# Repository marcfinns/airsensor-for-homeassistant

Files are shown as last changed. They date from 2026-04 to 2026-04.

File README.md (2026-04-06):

# AirSensor

A multi-room air quality monitor built around ESPHome and Home Assistant. Each unit sits flush on the wall like a light switch — mains powered, fully self-contained, nothing to charge or manage. Built on the ESP32-C6, it is hardware-ready for Matter, making it future-proof as smart home standards evolve.

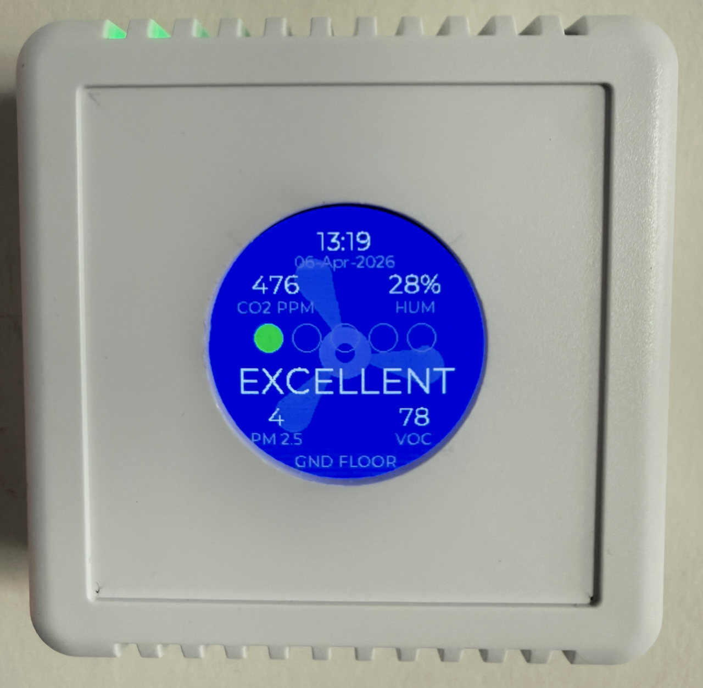
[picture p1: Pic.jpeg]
AirSensor unit installed on the wall


---

## What it measures

Each unit reports the following to Home Assistant in real time:

| Sensor | Measurements |
|---|---|
| **Sensirion SEN55** | PM1.0, PM2.5, PM4.0, PM10 · VOC Index · NOx Index · Temperature · Humidity |
| **Sensirion SCD4x** | CO2 (ppm) · Temperature · Humidity |
| **Infineon DPS310** *(optional)* | Barometric pressure · Temperature |

The DPS310 pressure sensor is fitted on one unit only and is entirely optional — the PCB and firmware support it but work fine without it.

---

## Display

Each unit has a **GC9A01A 240×240 round TFT** (SPI), sourced from AliExpress:

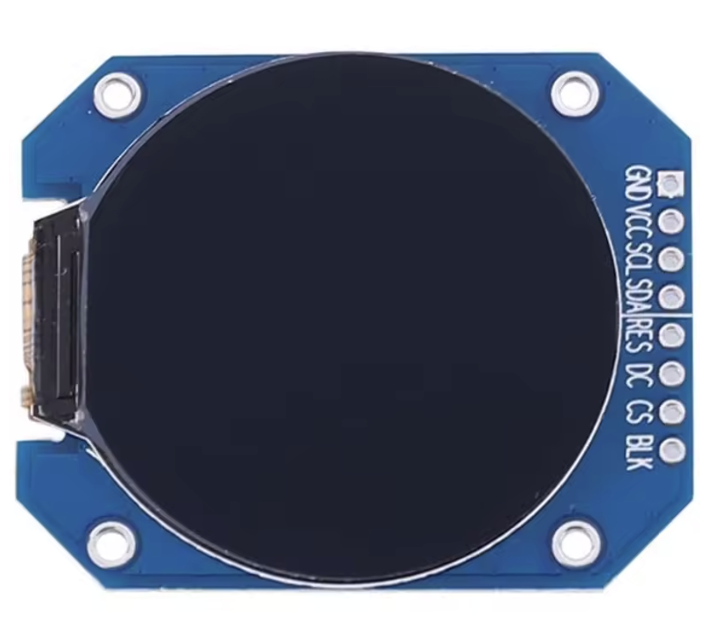
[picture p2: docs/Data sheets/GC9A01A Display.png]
GC9A01A round display module


The display shows:
- **Time and date** (synced from Home Assistant)
- **CO2, humidity, PM2.5, VOC** values in the four quadrants
- A **5-segment AQI bar** reflecting the worst pollutant level across all sensors, colour-coded from green (Excellent) to red (Very Poor)
- A large **status word** (EXCELLENT / GOOD / FAIR / POOR / VERY POOR) at the centre
- An **animated fan graphic** as the background (see below)

The XIAO's built-in RGB LED *(optional)* breathes in the AQI colour — green through red depending on air quality — visible from across the room without looking at the display. It can be enabled or disabled from Home Assistant and the state persists across reboots.

---

## Animated fan

A **Fan Speed** entity (Off / Low / High) is exposed in Home Assistant. Selecting Low or High drives an animated three-blade fan spinning in the background of the display — slow and blue-purple at Low, faster and brighter purple at High. It is purely decorative and does not control any physical hardware. The selected speed persists across reboots.

---

## Hardware

| Component | Role |
|---|---|
| Seeed XIAO ESP32-C3 | MCU — different GPIO layout, otherwise identical firmware |
| Seeed XIAO ESP32-C6 | MCU — preferred variant; Wi-Fi 6, Matter-capable radio |
| Sensirion SEN55 | Particulate matter + VOC + NOx + T/RH |
| Sensirion SCD4x | CO2 + T/RH |
| Infineon DPS310 breakout | Barometric pressure *(optional)* |
| GC9A01A 240×240 round TFT | Round display (AliExpress) |
| Kradex Z123_W | Enclosure — standard wall-mount junction box |

The ESP32-C6 is the preferred variant. Its Wi-Fi 6 and IEEE 802.15.4 radio make it hardware-ready for Matter once ESPHome's Matter support matures. The C3 lacks the necessary radio and cannot support Matter.

---

## PCB

A single custom PCB designed in KiCad houses the MCU, sensors, and display connector inside the Kradex enclosure.

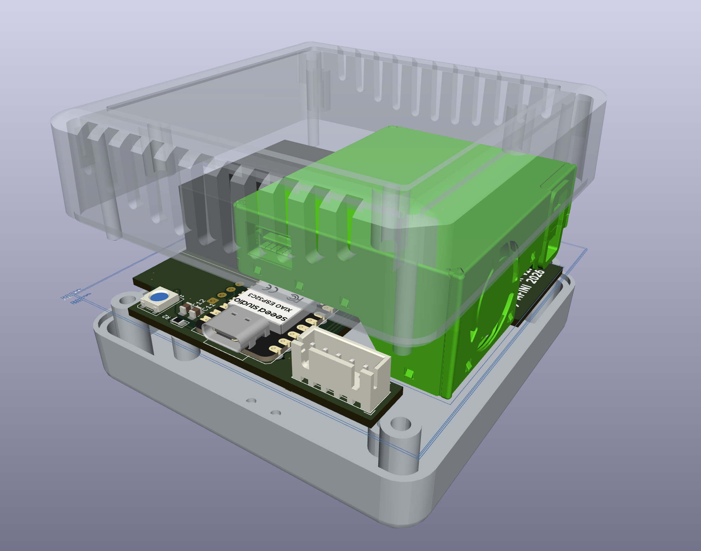
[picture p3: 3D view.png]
KiCad 3D render


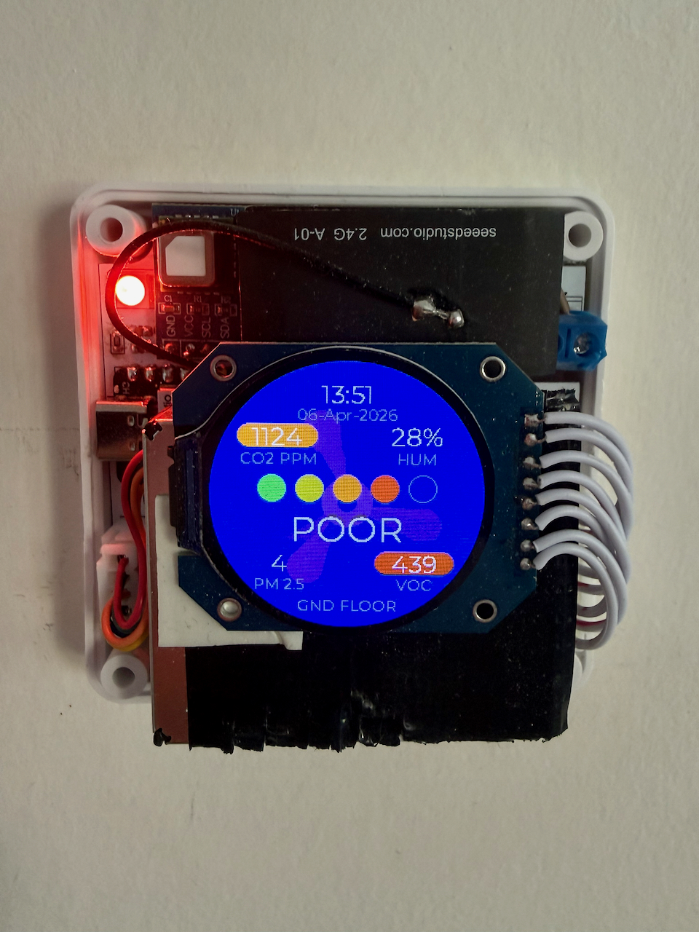
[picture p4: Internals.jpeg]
Internals — PCB, display and wiring mounted in the enclosure


Custom KiCad libraries (symbols, footprints, and 3D models) are kept under `lib/` and referenced with portable `${KIPRJMOD}`-relative paths so the project opens correctly on any machine.

---

## Home Assistant integration

Each unit exposes the following entities:

- **Sensors** — all measured values listed above
- **Fan Speed** — select (Off / Low / High) to control the display animation
- **Status LED** — switch to enable or disable the breathing LED
- **Display Backlight** — light entity with brightness control
- **Restart** — button to reboot the device OTA

---

## MCU variants

| | ESP32-C3 | ESP32-C6 |
|-|---|---|
| Wi-Fi | 802.11 b/g/n | 802.11 b/g/n/ax (Wi-Fi 6) |
| BLE | 5.0 | 5.3 |
| Matter (future) | No — hardware limitation | Yes — IEEE 802.15.4 radio |
| GPIO | Different pinout | Reference pinout |

Two reference templates are provided — `ESPHome_config/AirSensor-C3.yaml` and `AirSensor-C6.yaml` — covering both variants.

---

## Repository structure

```
AirSensor/
├── ESPHome_config/
│   ├── AirSensor-C3.yaml          # Reference template (ESP32-C3)
│   ├── AirSensor-C6.yaml          # Reference template (ESP32-C6)
│   ├── airsensor_aqi_helpers.h    # Shared AQI logic (C++)
│   ├── secrets.yaml               # Empty secrets template
│   └── private/                   # Real deployment configs (gitignored)
├── kicad/
│   └── AirSensor_display/         # KiCad project (schematic + PCB)
├── lib/
│   ├── symbols/                   # Custom KiCad symbols
│   ├── footprints/                # Custom KiCad footprints
│   └── 3d/                        # 3D models for KiCad
├── mech/                          # Enclosure and module STEP files
└── docs/
    └── Data sheets/               # Component datasheets
```

---

## Getting started

1. Copy `ESPHome_config/AirSensor-C3.yaml` or `AirSensor-C6.yaml` to `ESPHome_config/private/<unit-name>.yaml`
2. Fill in `ESPHome_config/private/secrets.yaml` (Wi-Fi credentials, API key, OTA password)
3. Search for `← CONFIGURE` markers in the YAML and update each one (device name, floor label, etc.)
4. Remove the DPS310 sensor block if the pressure sensor is not fitted
5. Flash via ESPHome: `esphome run private/<unit-name>.yaml`

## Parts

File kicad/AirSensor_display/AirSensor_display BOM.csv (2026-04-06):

Reference | Qty | Value | DNP | Exclude from BOM | Exclude from Board | Footprint | Datasheet
C1,C2,C5,C9,C11,C13 | 6 | 100nF |  |  |  | Capacitor_SMD:C_0805_2012Metric_Pad1.18x1.45mm_HandSolder | ~
C3,C4 | 2 | 47uF |  |  |  | Capacitor_SMD:C_0805_2012Metric_Pad1.18x1.45mm_HandSolder | ~
C6,C10,C12,C14 | 4 | 22uF |  |  |  | Capacitor_SMD:C_0805_2012Metric_Pad1.18x1.45mm_HandSolder | ~
D1 | 1 | WS2812B |  |  |  | LED_SMD:LED_WS2812B_PLCC4_5.0x5.0mm_P3.2mm | https://cdn-shop.adafruit.com/datasheets/WS2812B.pdf
D2 | 1 | SS12 |  |  |  | Diode_SMD:D_SMA | https://www.vishay.com/docs/88746/ss12.pdf
FB1 | 1 | 600ohm@100mhz |  |  |  | Inductor_SMD:L_0805_2012Metric | ~
J1 | 1 | SEN55 |  |  |  | Connector_JST:JST_XH_B5B-XH-A_1x05_P2.50mm_Vertical | ~
J2 | 1 | Screw_Terminal_01x02 |  |  |  | TerminalBlock_Phoenix:TerminalBlock_Phoenix_MKDS-1,5-2-5.08_1x02_P5.08mm_Horizontal | ~
J4 | 1 | Display |  |  |  | Connector_JST:JST_XH_B8B-XH-AM_1x08_P2.50mm_Vertical | ~
PS2 | 1 | HLK-PM01 |  |  |  | Converter_ACDC:Converter_ACDC_Hi-Link_HLK-PMxx | https://h.hlktech.com/download/ACDC%E7%94%B5%E6%BA%90%E6%A8%A1%E5%9D%973W%E7%B3%BB%E5%88%97/1/%E6%B5%B7%E5%87%8C%E7%A7%913W%E7%B3%BB%E5%88%97%E7%94%B5%E6%BA%9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
R2 | 1 | 220R |  |  |  | LED_SMD:LED_0805_2012Metric_Pad1.15x1.40mm_HandSolder | ~
R4 | 1 | 100R |  |  |  | LED_SMD:LED_0805_2012Metric_Pad1.15x1.40mm_HandSolder | ~
U1 | 1 | DC-DC 3V3 |  |  |  | Converter_DCDC:Converter_DCDC_Murata_OKI-78SR_Horizontal | https://power.murata.com/data/power/oki-78sr.pdf
U2 | 1 | DPS310 |  |  |  | AirSensor_footprints:DPS310_BREAKOUT
U3 | 1 | SCD41 |  |  |  | AirSensor_footprints:SCD41_BREAKOUT_1x4_2.54
U6 | 1 | MOUDLE-SEEEDUINO-XIAO-ESP32C3 |  |  |  | xiao ESP32C3_PCB:MOUDLE14P-SMD-2.54-21X17.8MM_PINONLY

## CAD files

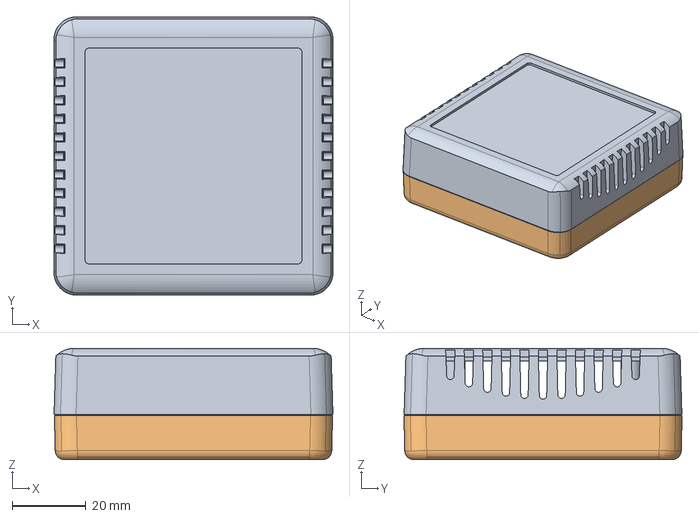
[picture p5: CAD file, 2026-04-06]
mech/Z123_W.stp
75.8 x 75.6 x 30.2 mm

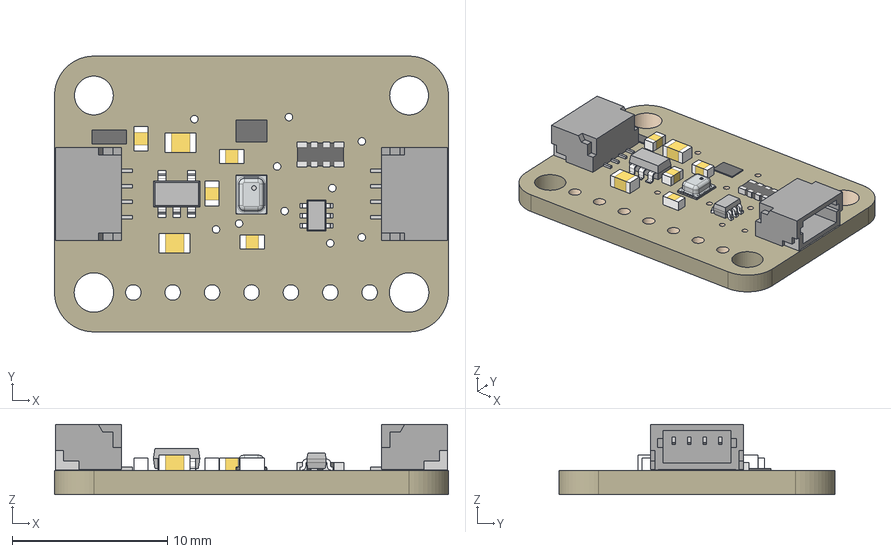
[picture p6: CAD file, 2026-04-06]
mech/4494-DPS310-Sensor.step
25.4 x 17.8 x 4.53 mm
Board
10uF x 2
AP2112K-3.3
10K x 4
10K_1
BSS138
STEMMA_I2C_QT x 2
GREEN
1N4148
BMX280_COMBO

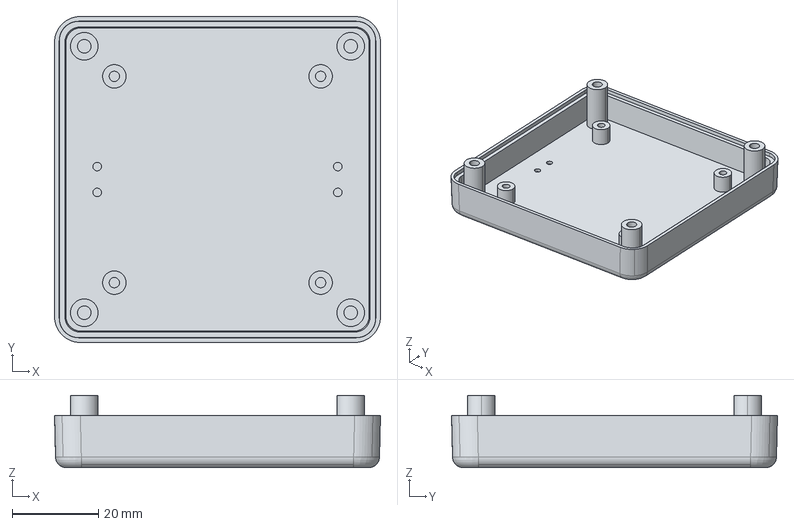
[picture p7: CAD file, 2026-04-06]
mech/Z123_W_BOTTOM.step
75.6 x 75.6 x 16.8 mm

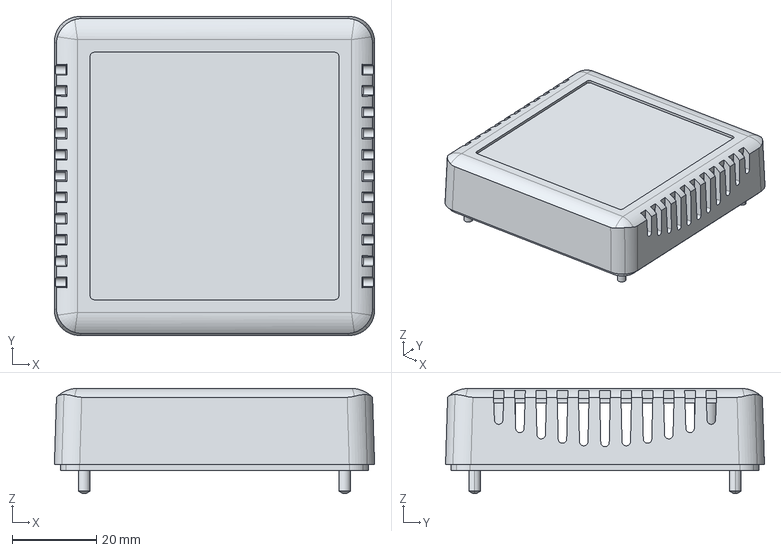
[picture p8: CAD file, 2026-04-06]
mech/Z123_W_TOP.step
75.8 x 75.5 x 24.9 mm

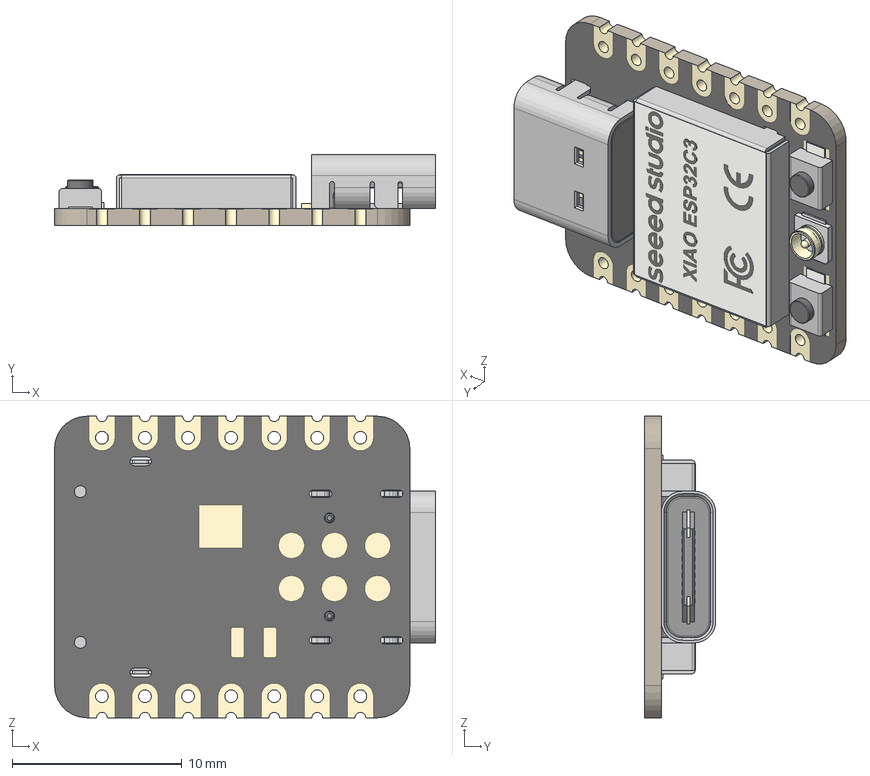
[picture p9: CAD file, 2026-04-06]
mech/seeed-studio-xiao-esp32-c3.step
22.5 x 4.21 x 17.8 mm
BOSS-EXTRUDE14_8_
BOSS-EXTRUDE7_4_
BOSS-EXTRUDE7_3_
BOSS-EXTRUDE14_4_
BOSS-EXTRUDE14_2_
BOSS-EXTRUDE14_11_
BOSS-EXTRUDE7_7_
BOSS-EXTRUDE14_9_
BOSS-EXTRUDE14_3_
BOSS-EXTRUDE14_7_
MIRROR2
BOSS-EXTRUDE14_5_
BOSS-EXTRUDE14_12_
BOSS-EXTRUDE7_8_
BOSS-EXTRUDE7_1_
BOSS-EXTRUDE14_10_
BOSS-EXTRUDE7_9_
BOSS-EXTRUDE14_6_
BOSS-EXTRUDE14_1_
BOSS-EXTRUDE7_6_
BOSS-EXTRUDE7_2_
CUT-EXTRUDE5
BOSS-EXTRUDE7_5_
U.FL Connector v1
Button (1) x 2
Shield

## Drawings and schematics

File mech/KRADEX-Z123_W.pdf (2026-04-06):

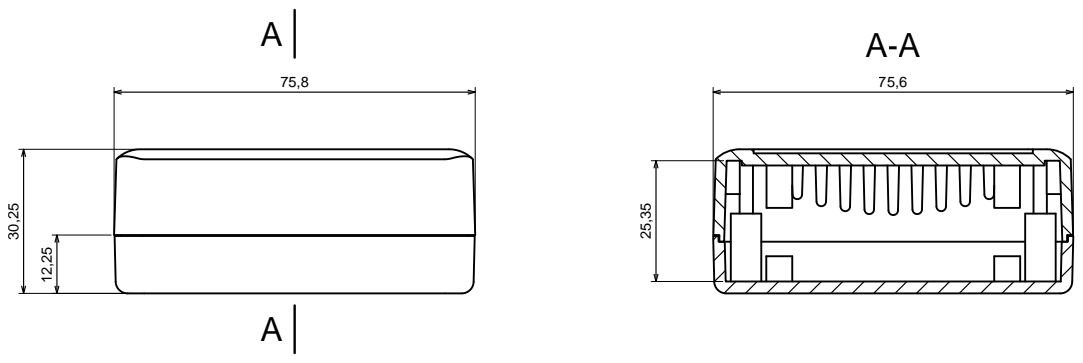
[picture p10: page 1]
Product model Format: A3 Scale 1:1; Tolerance: +/- 0.5 Material: PS, ABS Enclosure Z123 - assembly All rights reserved, Copyright Kradex 2016 AA

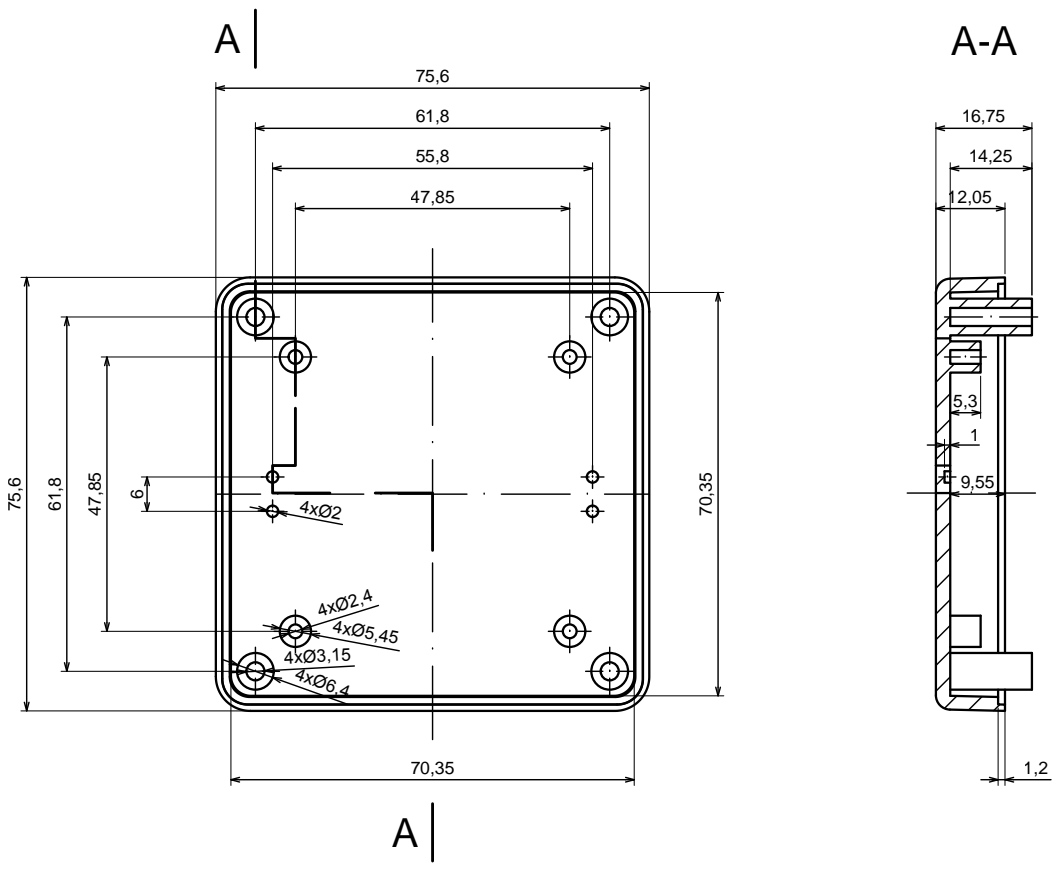
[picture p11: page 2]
Product model Format: A3 Scale 1:1; Tolerance: +/- 0.5 Material: PS, ABS Enclosure Z123 - base All rights reserved, Copyright Kradex 2016 A

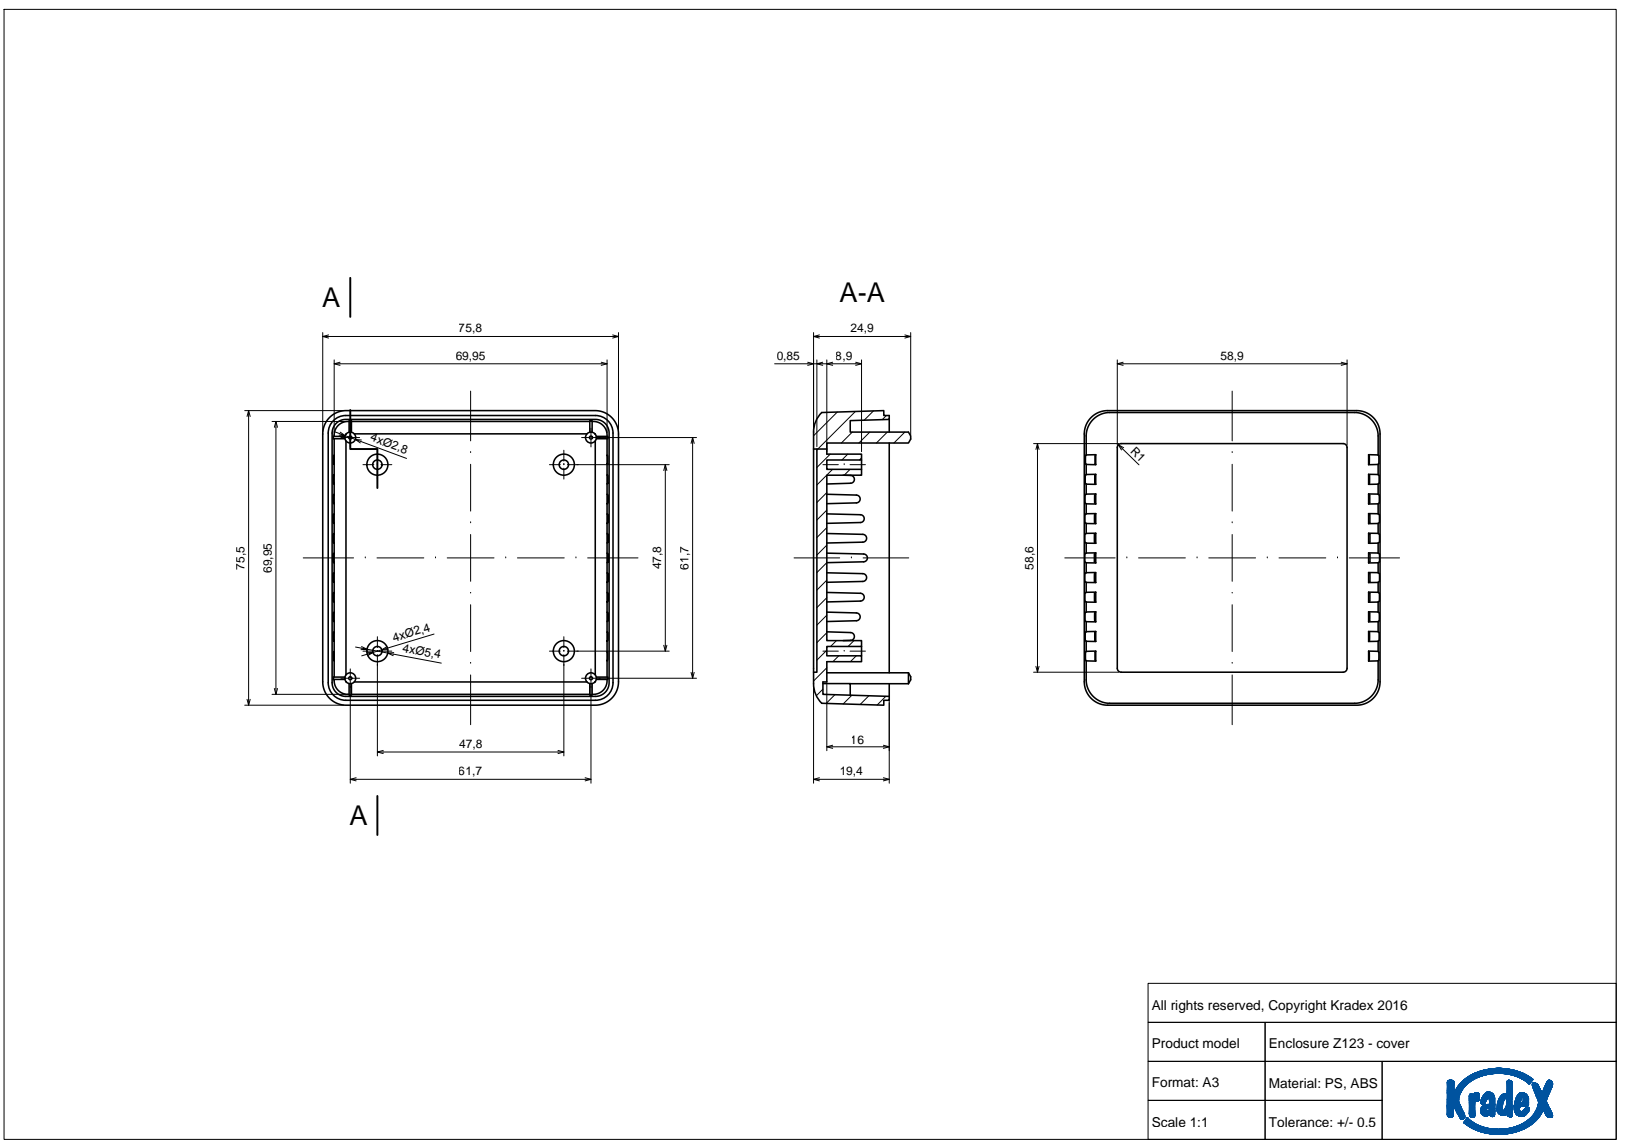
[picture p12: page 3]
Product model Format: A3 Scale 1:1; Tolerance: +/- 0.5 Material: PS, ABS Enclosure Z123 - cover All rights reserved, Copyright Kradex 2016 A A

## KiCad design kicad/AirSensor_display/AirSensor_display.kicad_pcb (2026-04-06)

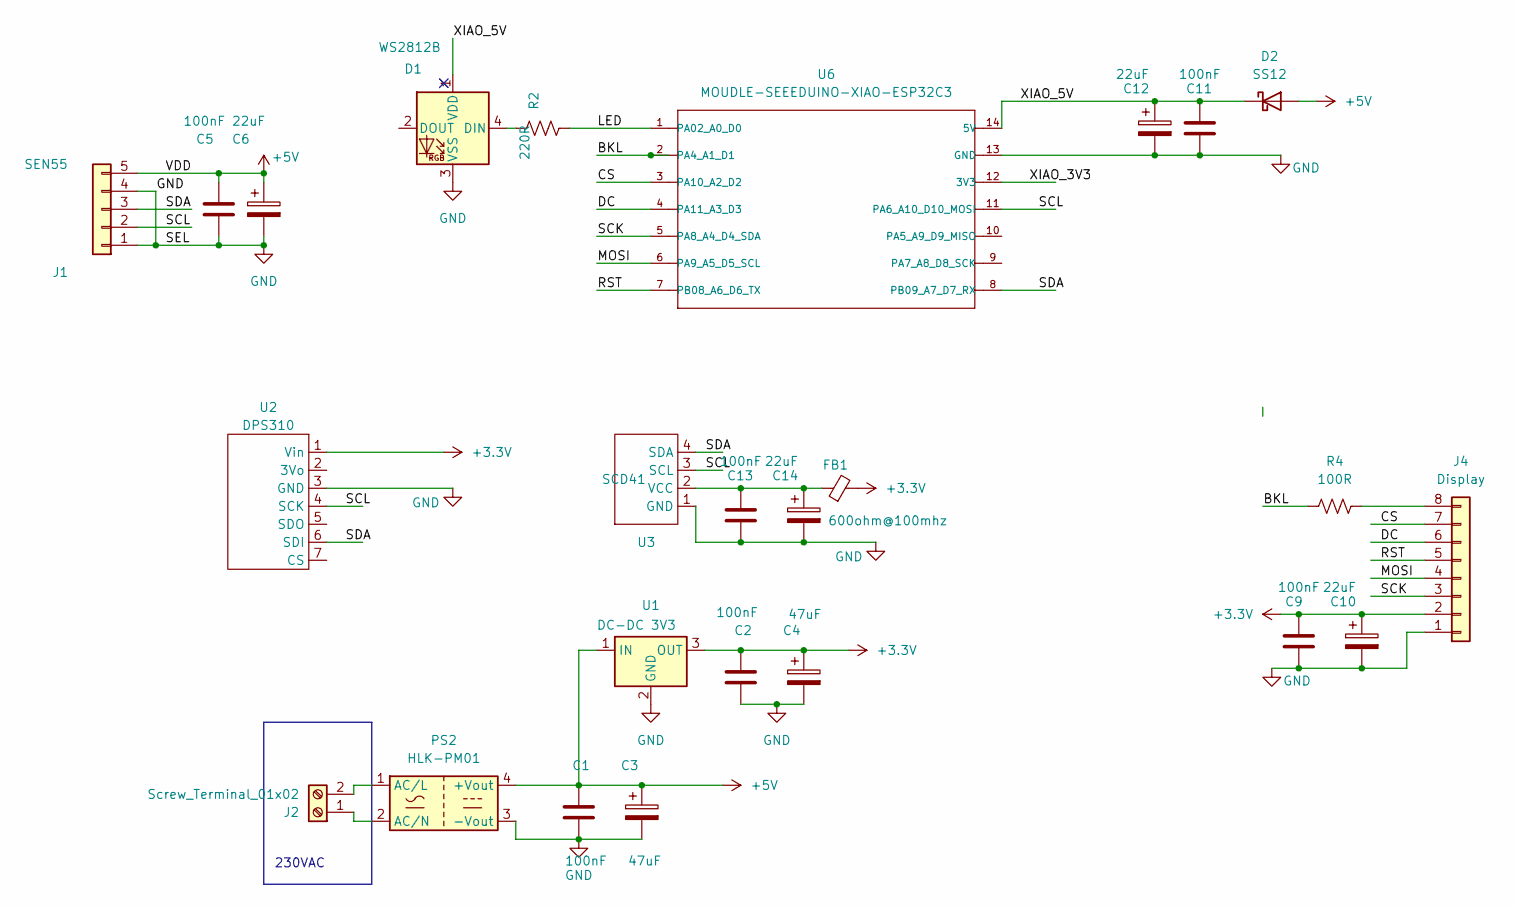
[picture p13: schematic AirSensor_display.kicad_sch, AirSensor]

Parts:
C1, C2, C5, C9, C11, C13: 100nF; C_0805_2012Metric_Pad1.18x1.45mm_HandSolder
C3, C4: 47uF; C_0805_2012Metric_Pad1.18x1.45mm_HandSolder
C6, C10, C12, C14: 22uF; C_0805_2012Metric_Pad1.18x1.45mm_HandSolder
D1: WS2812B; LED_WS2812B_PLCC4_5.0x5.0mm_P3.2mm
D2: SS12; D_SMA
FB1: 600ohm@100mhz; L_0805_2012Metric
J1: SEN55; JST_XH_B5B-XH-A_1x05_P2.50mm_Vertical
J2: Screw_Terminal_01x02; TerminalBlock_Phoenix_MKDS-1,5-2-5.08_1x02_P5.08mm_Horizont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
J4: Display; JST_XH_B8B-XH-AM_1x08_P2.50mm_Vertical
PS2: HLK-PM01; Converter_ACDC_Hi-Link_HLK-PMxx
R2: 220R; LED_0805_2012Metric_Pad1.15x1.40mm_HandSolder
R4: 100R; LED_0805_2012Metric_Pad1.15x1.40mm_HandSolder
U1: DC-DC 3V3; Converter_DCDC_Murata_OKI-78SR_Horizontal
U2: DPS310; DPS310_BREAKOUT
U3: SCD41; SCD41_BREAKOUT_1x4_2.54
U6: MOUDLE-SEEEDUINO-XIAO-ESP32C3; MOUDLE14P-SMD-2.54-21X17.8MM_PINONLY

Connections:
+3.3V: C2.1, C4.1, C9.1, C10.1, FB1.2, J4.2, U1.3 (OUT), U2.1 (Vin)
+5V: C1.1, C3.1, C5.1, C6.1, D2.2 (A), J1.5, PS2.4 (+Vout), U1.1 (IN)
/BKL: R4.2, U6.2 (PA4_A1_D1)
/CS: J4.7, U6.3 (PA10_A2_D2)
/DC: J4.6, U6.4 (PA11_A3_D3)
/LED: R2.1, U6.1 (PA02_A0_D0)
/MOSI: J4.4, U6.6 (PA9_A5_D5_SCL)
/RST: J4.5, U6.7 (PB08_A6_D6_TX)
/SCK: J4.3, U6.5 (PA8_A4_D4_SDA)
/SCL: J1.2, U2.4 (SCK), U3.3 (SCL), U6.11 (PA6_A10_D10_MOSI)
/SDA: J1.3, U2.6 (SDI), U3.4 (SDA), U6.8 (PB09_A7_D7_RX)
/XIAO_3V3: U6.12 (3V3)
/XIAO_5V: C11.1, C12.1, D1.1 (VDD), D2.1 (K), U6.14 (5V)
GND: C1.2, C2.2, C3.2, C4.2, C5.2, C6.2, C9.2, C10.2, C11.2, C12.2, C13.2, C14.2, D1.3 (VSS), J1.1, J1.4, J4.1, PS2.3 (-Vout), U1.2 (GND), U2.3 (GND), U3.1 (GND), U6.13 (GND)
unnamed: D1.4 (DIN), R2.2
unnamed: J2.1, PS2.2 (AC/N)
unnamed: J2.2, PS2.1 (AC/L)
unnamed: J4.8, R4.1
unnamed: C13.1, C14.1, FB1.1, U3.2 (VCC)

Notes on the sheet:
230VAC

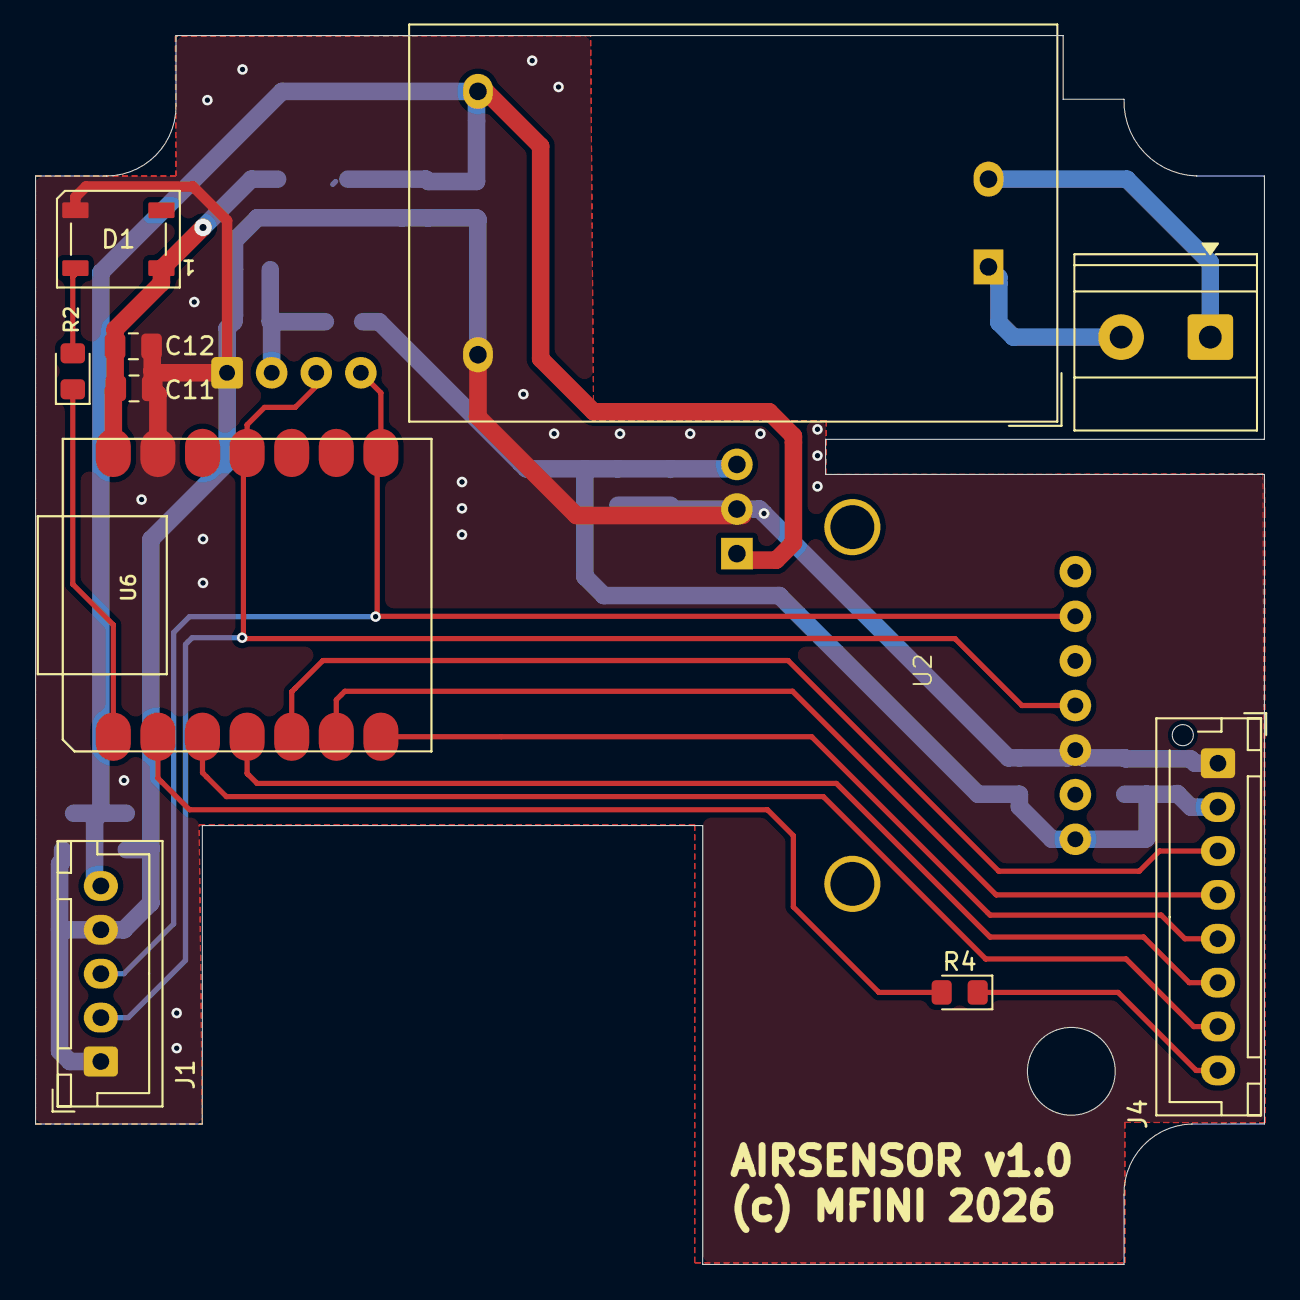
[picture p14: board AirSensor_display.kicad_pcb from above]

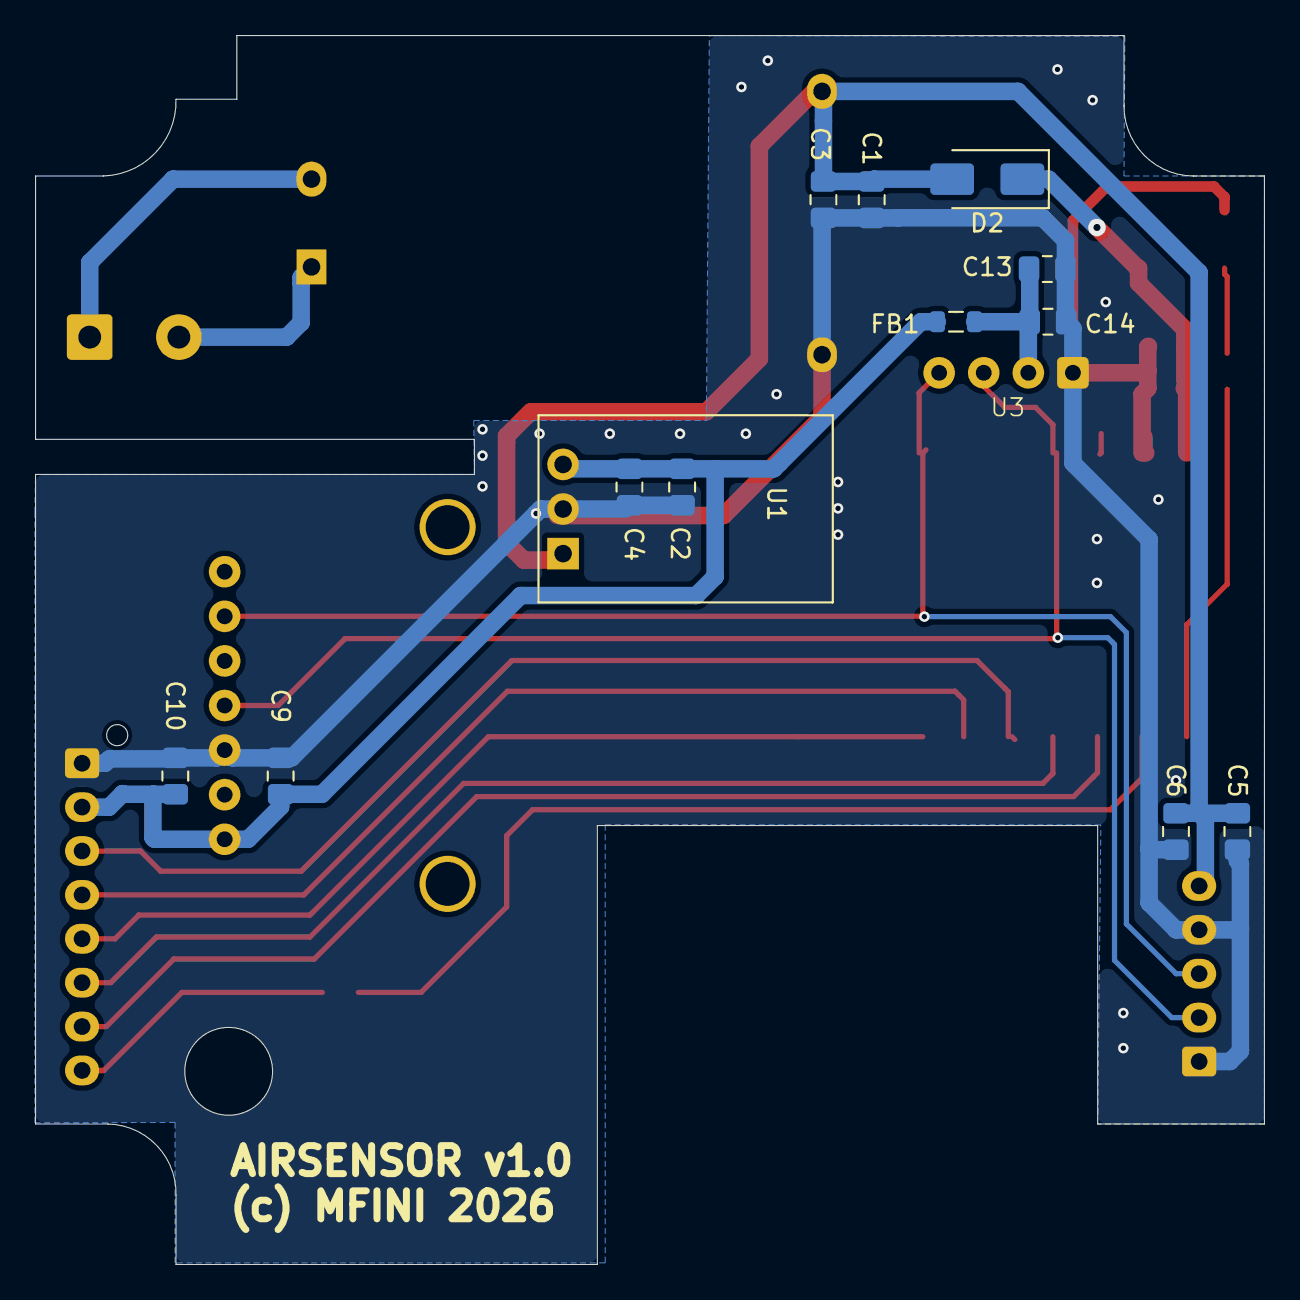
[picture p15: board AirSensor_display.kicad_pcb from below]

Board: 2 copper layers, 70.0 x 70.0 mm, 25 parts (14 on the bottom side), 18 nets.

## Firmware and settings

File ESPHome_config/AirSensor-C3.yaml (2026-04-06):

# =============================================================================
# AirSensor — Reference implementation for Seeed XIAO ESP32-C3
#
# MCU     : Seeed XIAO ESP32-C3
# Sensors : SEN55 (PM1/2.5/4/10, VOC, NOx, T, RH)
#           SCD4x (CO2, T, RH)
#           DPS310 (atmospheric pressure, optional — remove if not fitted)
# Display : GC9A01A 240×240 round TFT (SPI)
#
# To create a new unit from this template:
#   1. Copy to private/<unit-name>.yaml
#   2. Replace every value marked  ← CONFIGURE
#   3. Fill in private/secrets.yaml
# =============================================================================

esphome:
  name: airsensor-xxx            # ← CONFIGURE: unique lowercase device name
  friendly_name: Air Sensor XXX  # ← CONFIGURE: display name shown in HA
  includes:
    - ../airsensor_aqi_helpers.h   # AQI level/colour helpers shared by all units
  on_boot:
    # Priority -100 runs after all components are initialised.
    # Clears the boot-phase flag so the LED switch can start persisting state,
    # then publishes the restored LED enabled value to sync the HA entity.
    - priority: -100
      then:
        - lambda: |-
            id(g_boot_phase) = false;
            id(led_switch).publish_state(id(g_led_enabled));

# ---------------------------------------------------------------------------
# PREFERENCES
# ---------------------------------------------------------------------------
# Disable the automatic delayed-write to NVS flash.  Preference values
# (e.g. g_led_enabled) are written immediately when changed instead of
# being batched.  Keeps state reliable at the cost of slightly more flash
# wear on every toggle — acceptable given the low toggle frequency.
preferences:
  flash_write_interval: 0s

# ---------------------------------------------------------------------------
# MCU / FRAMEWORK
# ---------------------------------------------------------------------------
# ESP32-C3 — note different GPIO numbering compared to the C6 variant.
esp32:
  board: seeed_xiao_esp32c3
  variant: ESP32C3
  framework:
    type: esp-idf

# ---------------------------------------------------------------------------
# LOGGING
# ---------------------------------------------------------------------------
logger:
  level: INFO

# ---------------------------------------------------------------------------
# API / HOME ASSISTANT
# ---------------------------------------------------------------------------
api:
  encryption:
    key: !secret api_encryption_key

# Time source from Home Assistant (used for display)
time:
  - platform: homeassistant
    id: ha_time

# ---------------------------------------------------------------------------
# BLE / PROXY
# ---------------------------------------------------------------------------
# Kept for reference — disabled because enabling BLE on ESP32-C3 alongside
# Wi-Fi and a fast SPI display causes interference and CPU contention.
# bluetooth_proxy:
#   active: true
#
# esp32_ble_tracker:
#   scan_parameters:
#     interval: 1100ms
#     window: 1100ms
#     active: true

# ---------------------------------------------------------------------------
# OTA
# ---------------------------------------------------------------------------
ota:
  - platform: esphome
    password: !secret ota_password

# ---------------------------------------------------------------------------
# RESTART BUTTON (HOME ASSISTANT)
# ---------------------------------------------------------------------------
button:
  - platform: restart
    name: "AirSensor XXX Restart"  # ← CONFIGURE: match friendly_name

# ---------------------------------------------------------------------------
# WIFI
# ---------------------------------------------------------------------------
wifi:
  ssid: !secret wifi_ssid
  password: !secret wifi_password
  fast_connect: false
  power_save_mode: none
  ap:
    ssid: "AirSensor-XXX-Fallback"      # ← CONFIGURE: unique fallback SSID
    password: !secret fallback_hotspot_password

# ---------------------------------------------------------------------------
# HTTP UI (BASIC STATUS)
# ---------------------------------------------------------------------------
web_server:
  port: 80

# ---------------------------------------------------------------------------
# I2C BUS (SENSORS)
# ---------------------------------------------------------------------------
# C3 pinout: SDA=GPIO20, SCL=GPIO10.  SEN55, SCD4x and DPS310 share this bus.
i2c:
  sda: GPIO20
  scl: GPIO10
  scan: true
  id: bus_a
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

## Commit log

2026-04-06 Initial release
    Multi-room air quality monitor: ESPHome firmware for Seeed XIAO ESP32-C3/C6,
    KiCad PCB, custom component libraries, datasheets, and photos.
    [4494-DPS310-Sensor.step, AirSensor_display BOM.csv, AirSensor_display.kicad_pcb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]
2026-04-06 Update README
    - Remove mention of specific deployment count
    - Add multicolor breathing LED (optional)
    - Fix Matter: C3 hardware limitation, C6 has IEEE 802.15.4 radio
